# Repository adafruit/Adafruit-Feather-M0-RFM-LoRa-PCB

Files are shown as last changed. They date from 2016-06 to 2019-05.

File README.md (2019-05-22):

## Adafruit Feather M0 RFM LoRa PCB
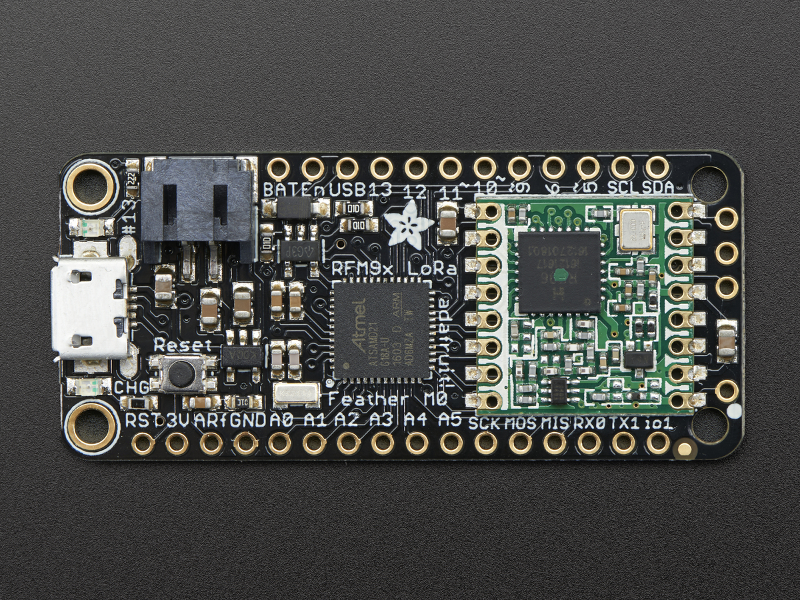
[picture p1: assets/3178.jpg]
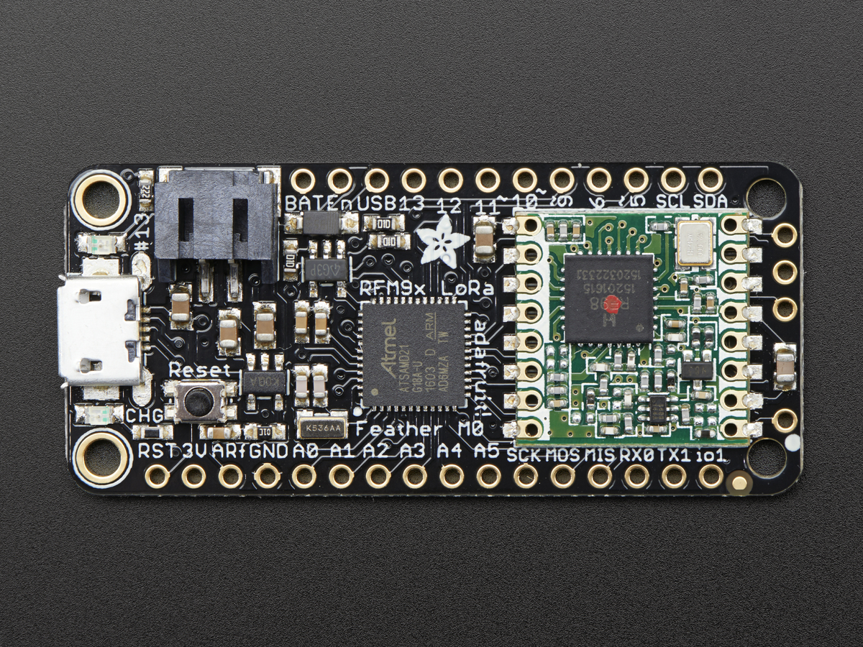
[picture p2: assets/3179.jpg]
&nbsp; <br />
Click to purchase from the Adafruit Shop:
- [Adafruit Feather M0 with RFM95 LoRa Radio - 900MHz - RadioFruit](https://www.adafruit.com/product/3178)
- [Adafruit Feather M0 RFM96 LoRa Radio - 433MHz - RadioFruit](https://www.adafruit.com/product/3179)

This is the Adafruit Feather M0 RFM95 LoRa Radio (900MHz). We call these RadioFruits, our take on an microcontroller with a "Long Range (LoRa)" packet radio transceiver with built in USB and battery charging. Its an Adafruit Feather M0 with a 900MHz radio module cooked in! Great for making wireless networks that are more flexible than Bluetooth LE and without the high power requirements of WiFi.

Feather is the new development board from Adafruit, and like its namesake it is thin, light, and lets you fly! We designed Feather to be a new standard for portable microcontroller cores.We have other boards in the Feather family, check'em out here.

This is the 900 MHz radio version, which can be used for either 868MHz or 915MHz transmission/reception - the exact radio frequency is determined when you load the software since it can be tuned around dynamically. We also sell a 433MHz version of the same radio chipset!

At the Feather M0's heart is an ATSAMD21G18 ARM Cortex M0 processor, clocked at 48 MHz and at 3.3V logic, the same one used in the new Arduino Zero. This chip has a whopping 256K of FLASH (8x more than the Atmega328 or 32u4) and 32K of RAM (16x as much)! This chip comes with built in USB so it has USB-to-Serial program & debug capability built in with no need for an FTDI-like chip.

For more details, check out the product pages at

  * https://www.adafruit.com/product/3178
  * https://www.adafruit.com/product/3179
  
PCB files for the Adafruit Feather M0 RFM69 / RFM9X LoRa Radios. The format is EagleCAD schematic and board layout

### License

Adafruit invests time and resources providing this open source design, please support Adafruit and open-source hardware by purchasing products from [Adafruit](https://www.adafruit.com)!

All text above must be included in any redistribution

Designed by Limor Fried/Ladyada for Adafruit Industries.
Creative Commons Attribution/Share-Alike, all text above must be included in any redistribution. 
See license.txt for additional information.

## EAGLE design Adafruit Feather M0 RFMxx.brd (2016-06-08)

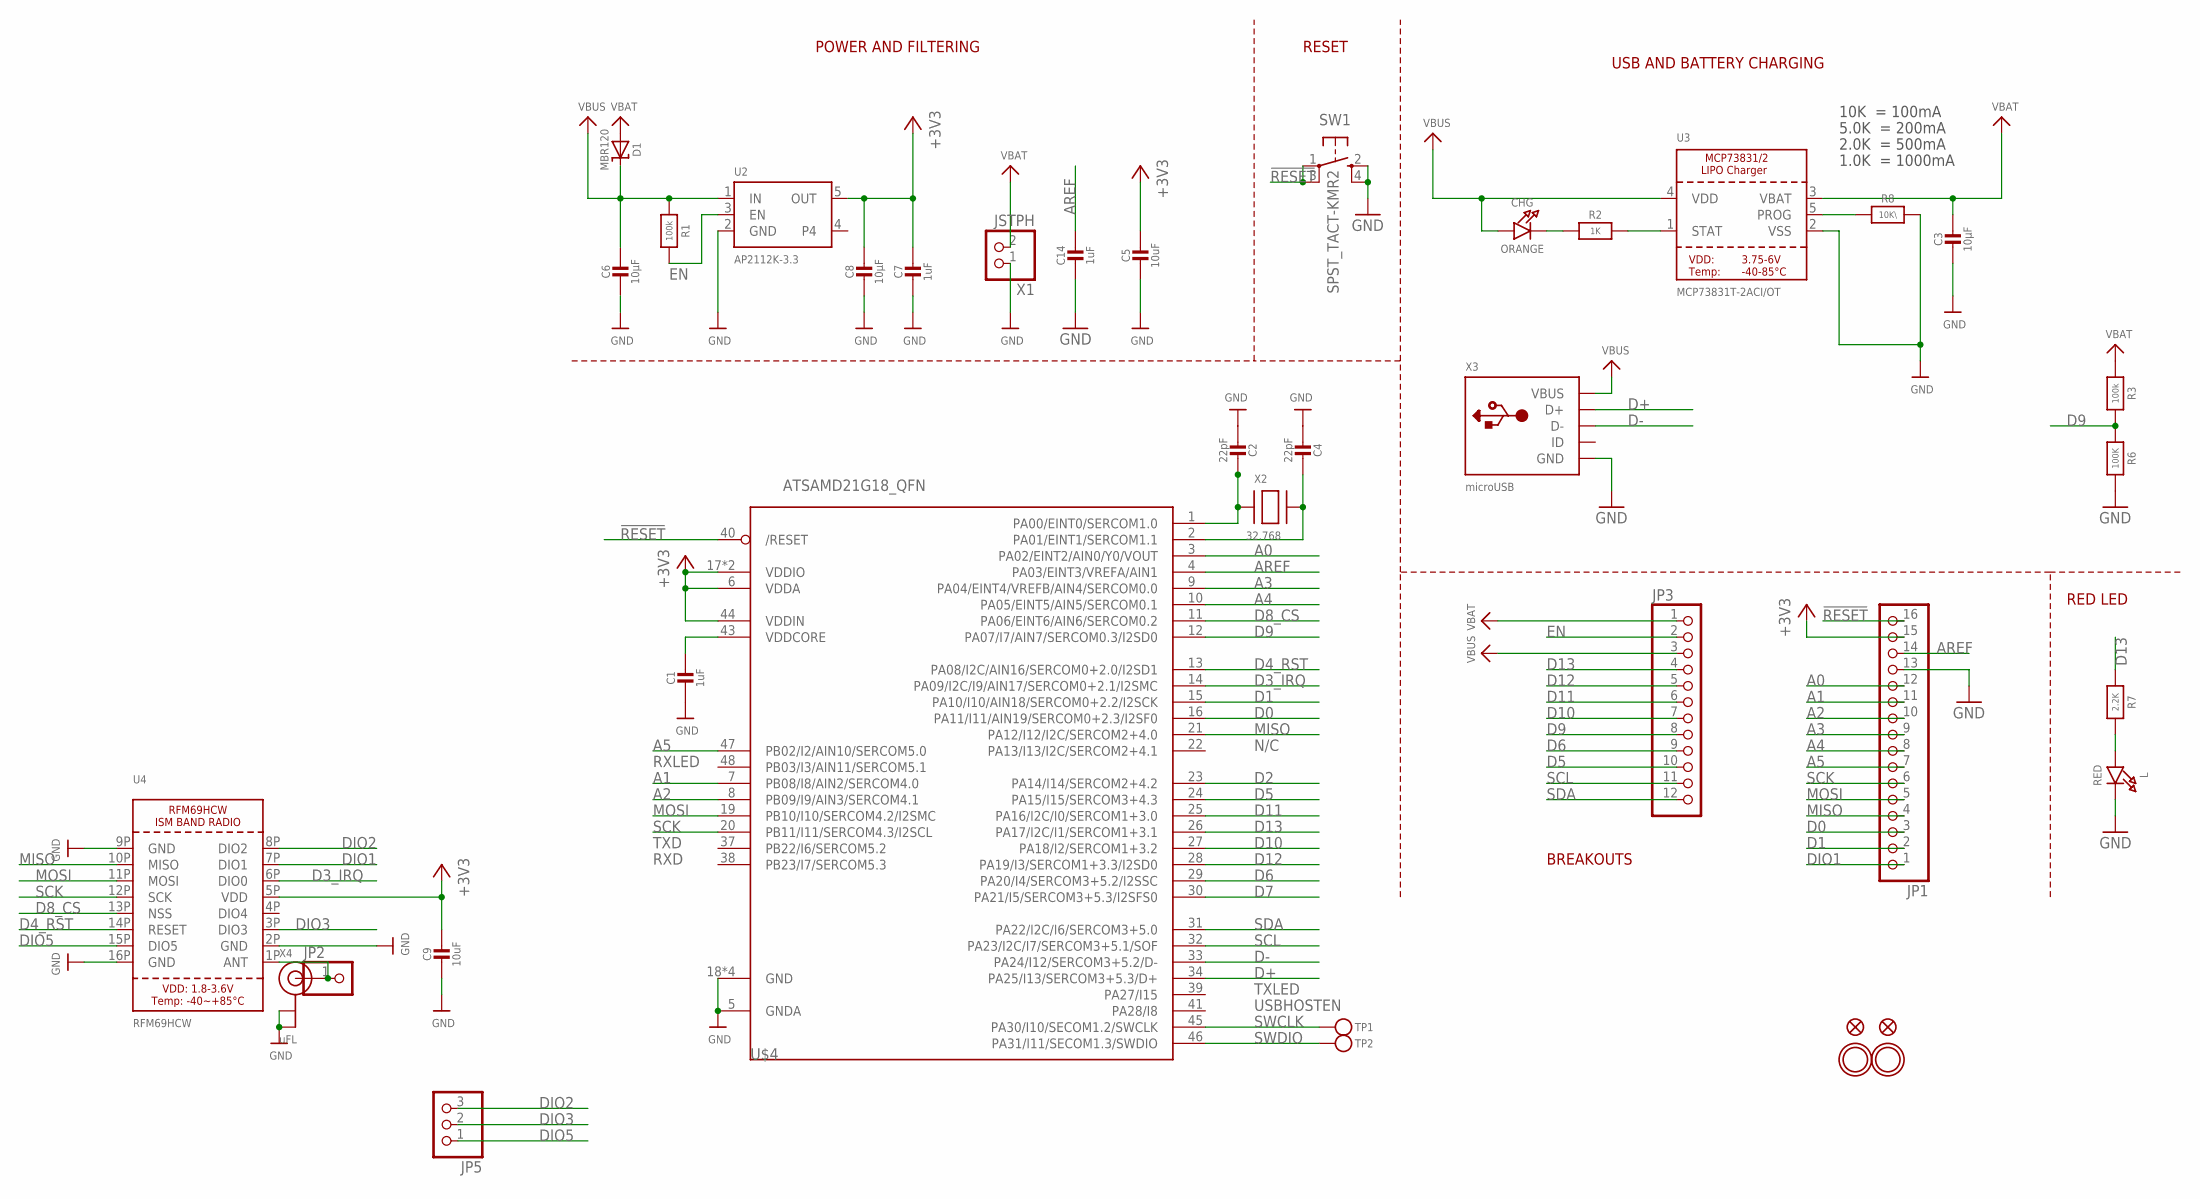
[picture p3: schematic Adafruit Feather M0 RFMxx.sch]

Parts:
C1, C7, C14: 1uF; 0603-NO
C2, C4: 22pF; 0603-NO
C3, C6, C8: 10µF; 0805-NO
C5, C9: 10uF; 0805-NO
CHG: ORANGE; CHIPLED_0805_NOOUTLINE
D1: MBR120; SOD-123
JP1: HEADER-1X16ROUND; 1X16_ROUND
JP2: HEADER-1X1ROUND; 1X01_ROUND
JP3: HEADER-1X12; 1X12_ROUND
JP5: HEADER-1X3ROUND; 1X03_ROUND
L: RED; CHIPLED_0805_NOOUTLINE
R1, R3: 100k; 0603-NO
R2: 1K; 0603-NO
R6: 100K; 0603-NO
R7: 2.2K; 0603-NO
R8: 10K\; 0603-NO
SW1: SPST_TACT-KMR2; KMR2
TP1, TP2: TESTPOINTROUND1.5MM; TESTPOINT_ROUND_1.5MM
U2: AP2112K-3.3; SOT23-5
U3: MCP73831T-2ACI/OT; SOT23-5
U4: RFM69HCW; RFMHCW_SMT
U$4: ATSAMD21G18_QFN; TQFN48_7MM
U$31, U$32: MOUNTINGHOLE2.5; MOUNTINGHOLE_2.5_PLATED
U$34, U$35: FIDUCIAL""; FIDUCIAL_1MM
X1: JSTPH; JSTPH2
X2: 32.768; XTAL3215
X3: microUSB; 4UCONN_20329_V2
X4: uFL; U.FL

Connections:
!RESET: JP1.16, SW1.1, SW1.3 (P1), U$4.40 (/RESET)
+3V3: C5.1, C7.1, C8.1, C9.1, JP1.15, U2.5 (OUT), U4.5P (VDD), U$4.6 (VDDA), U$4.17 (VDDIO), U$4.36 (VDDIO), U$4.44 (VDDIN)
A0: JP1.12, U$4.3 (PA02/EINT2/AIN0/Y0/VOUT)
A1: JP1.11, U$4.7 (PB08/I8/AIN2/SERCOM4.0)
A2: JP1.10, U$4.8 (PB09/I9/AIN3/SERCOM4.1)
A3: JP1.9, U$4.9 (PA04/EINT4/VREFB/AIN4/SERCOM0.0)
A4: JP1.8, U$4.10 (PA05/EINT5/AIN5/SERCOM0.1)
A5: JP1.7, U$4.47 (PB02/I2/AIN10/SERCOM5.0)
ANT: JP2.1, U4.1P (ANT), X4.3 (SIGNAL)
AREF: C14.1, JP1.14, U$4.4 (PA03/EINT3/VREFA/AIN1)
D0: JP1.3, U$4.16 (PA11/I11/AIN19/SERCOM0+2.3/I2SF0)
D1: JP1.2, U$4.15 (PA10/I10/AIN18/SERCOM0+2.2/I2SCK)
D2: U$4.23 (PA14/I14/SERCOM2+4.2)
D3_IRQ: U4.6P (DIO0), U$4.14 (PA09/I2C/I9/AIN17/SERCOM0+2.1/I2SMC)
D4_RST: U4.14P (RESET), U$4.13 (PA08/I2C/AIN16/SERCOM0+2.0/I2SD1)
D5: JP3.10, U$4.24 (PA15/I15/SERCOM3+4.3)
D6: JP3.9, U$4.29 (PA20/I4/SERCOM3+5.2/I2SSC)
D7: U$4.30 (PA21/I5/SERCOM3+5.3/I2SFS0)
D8_CS: U4.13P (NSS), U$4.11 (PA06/EINT6/AIN6/SERCOM0.2)
D9: JP3.8, R3.2, R6.1, U$4.12 (PA07/I7/AIN7/SERCOM0.3/I2SD0)
D10: JP3.7, U$4.27 (PA18/I2/SERCOM1+3.2)
D11: JP3.6, U$4.25 (PA16/I2C/I0/SERCOM1+3.0)
D12: JP3.5, U$4.28 (PA19/I3/SERCOM1+3.3/I2SD0)
D13: JP3.4, R7.1, U$4.26 (PA17/I2C/I1/SERCOM1+3.1)
D+: U$4.34 (PA25/I13/SERCOM3+5.3/D+), X3.D+
D-: U$4.33 (PA24/I12/SERCOM3+5.2/D-), X3.D-
DIO1: JP1.1, U4.7P (DIO1)
DIO2: JP5.3, U4.8P (DIO2)
DIO3: JP5.2, U4.3P (DIO3)
DIO5: JP5.1, U4.15P (DIO5)
EN: JP3.2, R1.2, U2.3 (EN)
GND: C1.2, C2.2, C3.2, C4.2, C5.2, C6.2, C7.2, C8.2, C9.2, C14.2, JP1.13, L.C, R6.2, R8.2, SW1.2 (S), SW1.4 (S1), U2.2 (GND), U3.2 (VSS), U4.2P (GND), U4.9P (GND), U4.16P (GND), U$4.5 (GNDA), U$4.18 (GND), U$4.35 (GND), U$4.42 (GND), U$4.THERMAL (GND), X1.1, X3.BASE@1 (GND), X3.BASE@2 (GND), X3.GND, X3.SPRT@1 (GND), X3.SPRT@2 (GND), X3.SPRT@3 (GND), X3.SPRT@4 (GND), X4.1 (GND), X4.2 (GND)
MISO: JP1.4, U4.10P (MISO), U$4.21 (PA12/I12/I2C/SERCOM2+4.0)
MOSI: JP1.5, U4.11P (MOSI), U$4.19 (PB10/I10/SERCOM4.2/I2SMC)
unnamed: CHG.C, R2.1
unnamed: L.A, R7.2
unnamed: R2.2, U3.1 (STAT)
unnamed: R8.1, U3.5 (PROG)
unnamed: C2.1, U$4.1 (PA00/EINT0/SERCOM1.0), X2.P$1
unnamed: C4.1, U$4.2 (PA01/EINT1/SERCOM1.1), X2.P$2
SCK: JP1.6, U4.12P (SCK), U$4.20 (PB11/I11/SERCOM4.3/I2SCL)
SCL: JP3.11, U$4.32 (PA23/I2C/I7/SERCOM3+5.1/SOF)
SDA: JP3.12, U$4.31 (PA22/I2C/I6/SERCOM3+5.0)
SWCLK: TP1.P$1, U$4.45 (PA30/I10/SECOM1.2/SWCLK)
SWDIO: TP2.P$1, U$4.46 (PA31/I11/SECOM1.3/SWDIO)
VBAT: C3.1, D1.A, JP3.1, R3.1, U3.3 (VBAT), X1.2
VBUS: C6.1, CHG.A, D1.C, JP3.3, R1.1, U2.1 (IN), U3.4 (VDD), X3.VBUS
VDDCORE: C1.1, U$4.43 (VDDCORE)

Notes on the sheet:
POWER AND FILTERING
RESET
10K = 100mA
5.0K = 200mA
2.0K = 500mA
1.0K = 1000mA
N/C
TXLED
USBHOSTEN
RXLED
TXD
RXD
USB AND BATTERY CHARGING
BREAKOUTS
RED LED

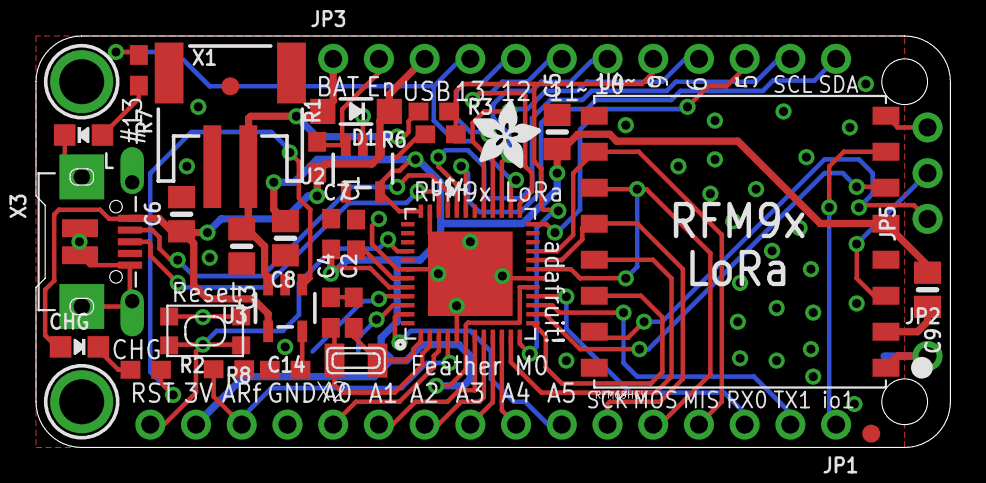
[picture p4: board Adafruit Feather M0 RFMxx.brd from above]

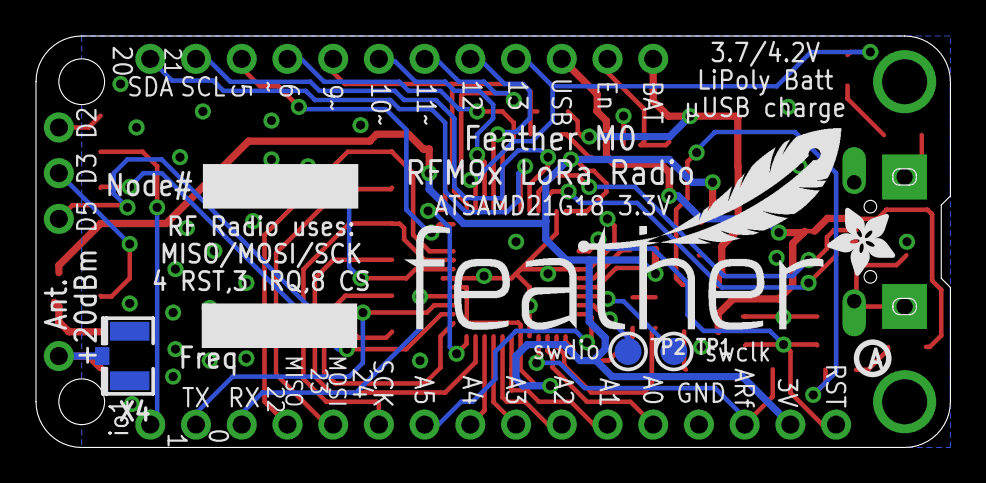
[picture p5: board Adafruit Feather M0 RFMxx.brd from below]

Board: 2 copper layers, 50.8 x 22.9 mm, 42 parts (6 on the bottom side), 46 nets.

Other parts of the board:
U$7, U$12: ADAFRUIT_3.5MM
U$9: FEATHERLOGO
U$13: PCBFEAT-REV-040

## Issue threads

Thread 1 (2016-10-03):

Bootloader for M0 Lora board

asprakash, 2016-10-03:
Hi Adafruit team,
I have cloned this board and trying to up the board. However, I am unable to find the bootloader/firmware for this board. Can you please point where can I get the bootloader from Adafruit for this board or Should I use the bootloader from Atmel for ATSAMD21G18A?. Any kind of input is appreciated.

TIA,
Prakash.

ladyada, 2016-10-03:
https://github.com/adafruit/ArduinoCore-samd

Closed 2016-10-03.

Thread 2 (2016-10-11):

USB port is not detected.

asprakash, 2016-10-11:
Thanks for your support. I tried adafruit bootloader for feather and the official hex file, featherm0bootloader_160305.hex and flashed by the jlink programmer. The LED is blinking like heart pulse. However, the USB port is not detected. On windows I am getting "USB port malfunction issue" and on Linux, I am getting the error, "unable to enumerate USB device on port 1". I can confirmed that getting the same issue on multiple boards.

I also checked this issue, https://github.com/arduino/ArduinoCore-samd/issues/137 So is there any bug on the Adafruit bootloader?.  Any kind of help is appreciated to solve this issue.

TIA,
Prakash

ladyada, 2016-10-11:
nope there's no bugs, we don't support DIY projects!

Closed 2016-10-11.

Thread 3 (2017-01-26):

SPI FAIL

estherbm, 2017-01-26:
Hi,
I am using the SPI with a sensor but it doesn't work. I have tried to put pin8 HIGH but doesn't work. Any idea?

ladyada, 2017-01-26:
tech support is handled in the adafruit forums, thx!

Closed 2017-01-26.

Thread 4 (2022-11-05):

Wrong IRQ pin number in the Feather M0 RFM69 pinout PDF

DeepCoreSystem, 2022-11-05:
Hi,
in the PDF with the Feather M0 RFM69 pinout, the IRQ pin is wrong.

When looking at the schematic, I see that the IRQ should be on pin 3, a.k.a. PA09

PeeJay, 2024-04-14:
Just took me hours to figure that out!

BlitzCityDIY, 2024-07-12:
prettypins has been updated

Closed 2024-07-12.

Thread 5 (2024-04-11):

Is it possible to make the library files available for this board?

ksanim, 2024-04-11:
Hi, I am building a remote IMU device with the Feather M0 RFM LoRa Microprocessor. I was wondering if the library files used to make this PCB can be made available? Thank you.

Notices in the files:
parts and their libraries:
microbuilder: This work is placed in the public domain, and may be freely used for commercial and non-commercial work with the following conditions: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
